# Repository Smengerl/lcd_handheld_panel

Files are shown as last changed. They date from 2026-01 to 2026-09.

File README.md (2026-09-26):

# Wireless Smart Home Control Panel

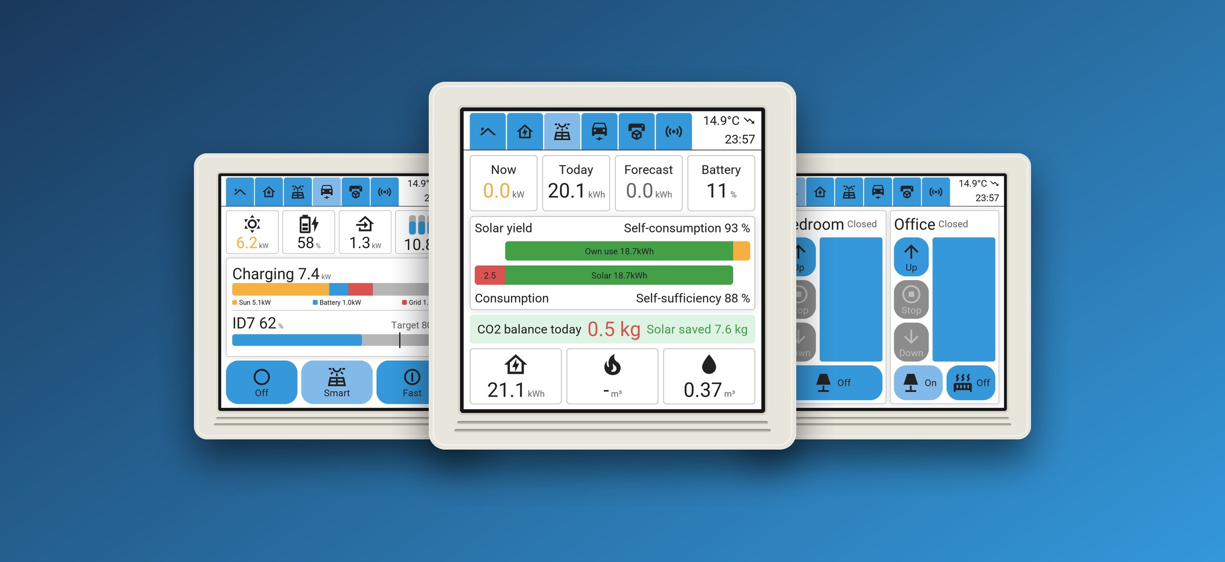
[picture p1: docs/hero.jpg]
Smart home control panel





A 3D-printed, battery-powered 4″ touchscreen (480×480) for Home Assistant, built with ESPHome and LVGL. It charges wirelessly via Qi and snaps onto its charger with a MagSafe-compatible magnetic ring.

## Table of Contents
- [Design](#design)
- [Examples](#examples)
- [3D-Printed Parts](#3d-printed-parts)
- [Standard Hardware](#standard-hardware)
- [Assembly](#assembly)
- [Software](#software)
- [Development](#development)
- [License](#license)
- [Authors](#authors)

## Design

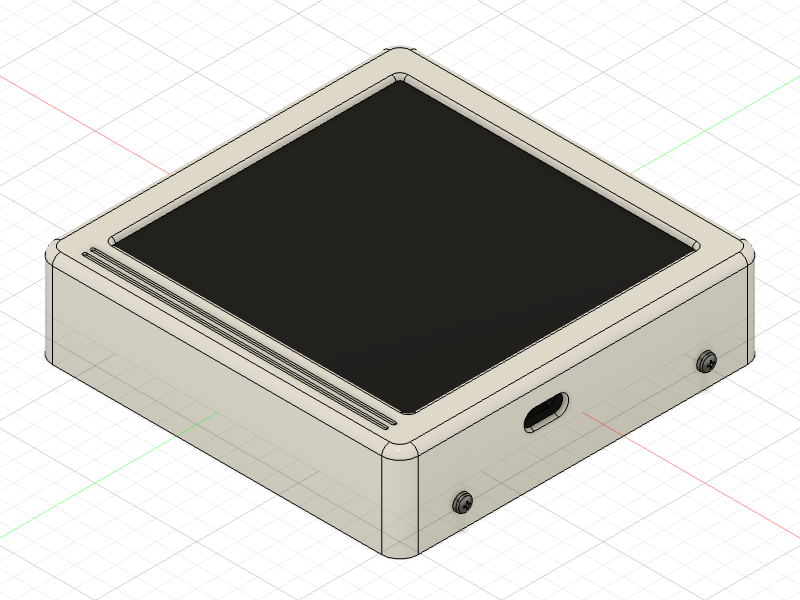
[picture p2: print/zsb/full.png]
Assembly overview


## Examples

Some of the pages I use on my own panels (ESPHome + LVGL, 480×480 px). The images are clean renderings of the real screens, drawn from the actual layout and design tokens.

| | | |
| :---: | :---: | :---: |
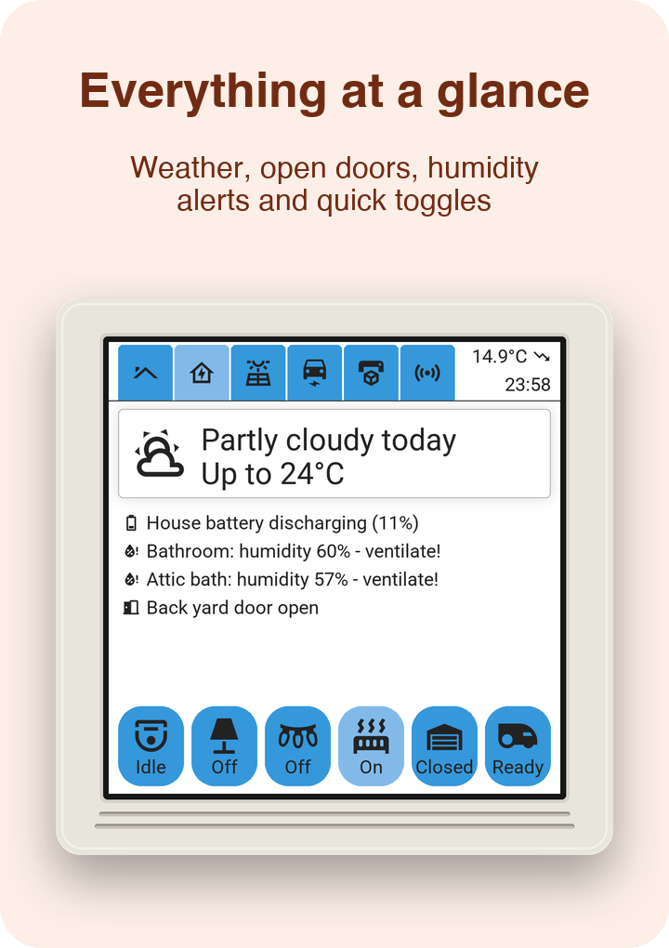
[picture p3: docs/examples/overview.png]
Overview page
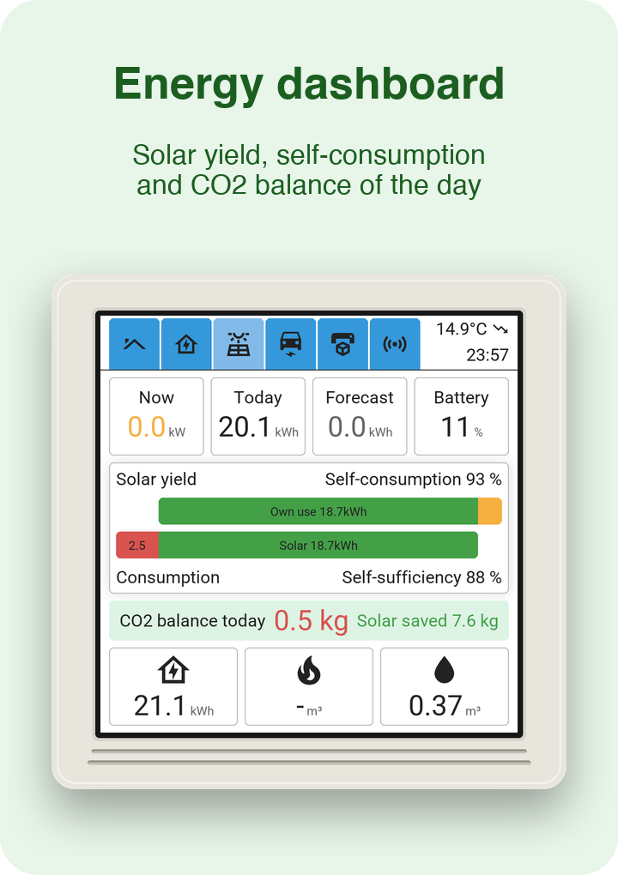
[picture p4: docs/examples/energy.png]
Energy page
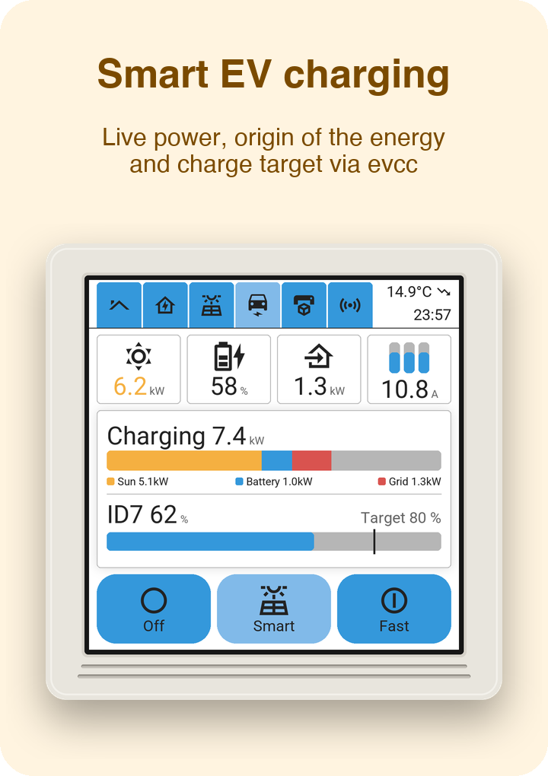
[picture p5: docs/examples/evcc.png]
EV charging page
|  |  |  |
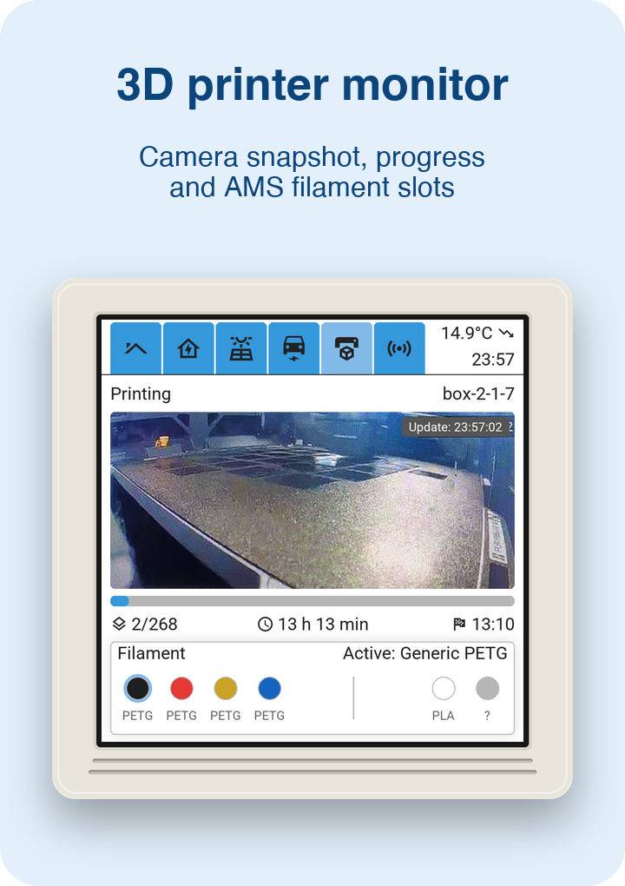
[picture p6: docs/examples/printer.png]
3D printer page
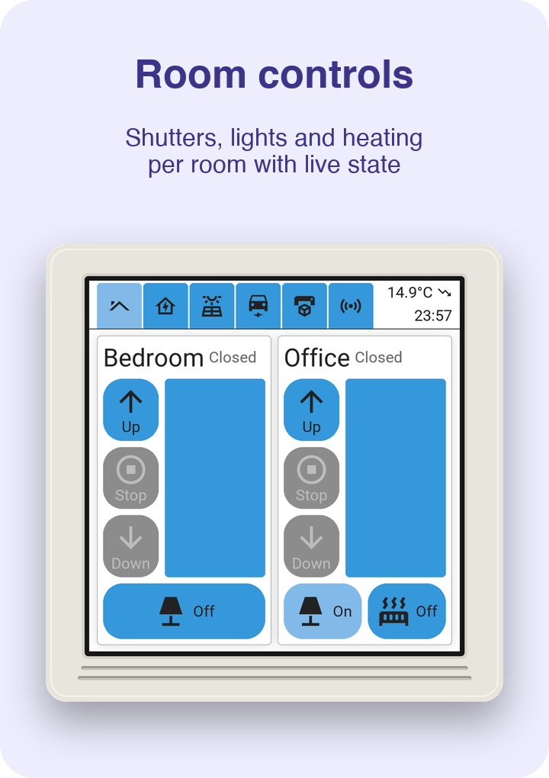
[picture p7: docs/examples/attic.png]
Room controls page
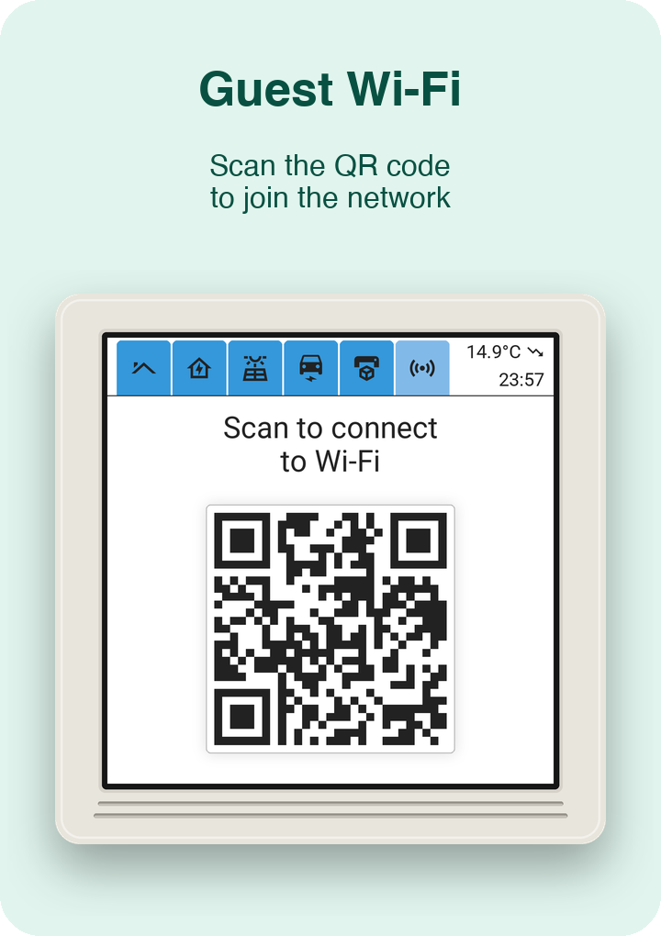
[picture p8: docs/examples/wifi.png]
Guest Wi-Fi page
|  |  |  |
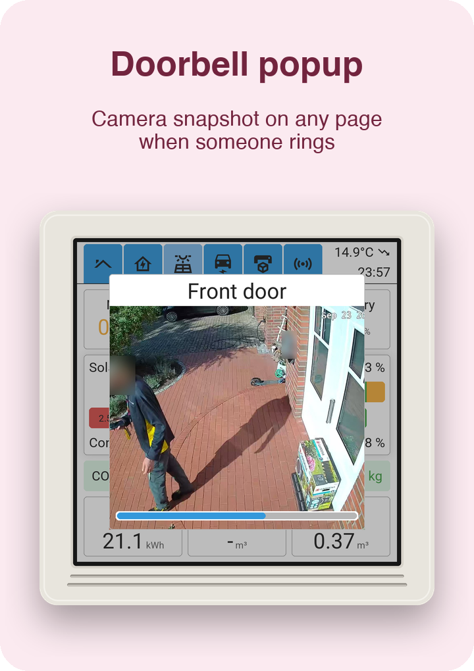
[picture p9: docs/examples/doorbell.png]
Doorbell popup
| |  | |

The example configuration in [`ha_scripts`](./ha_scripts) contains the room-controls page in exactly this design, together with the header, icon tab bar and design tokens, without any dependency on my setup. The other pages depend on specific integrations (solar inverter, [evcc](https://evcc.io), Bambu Lab printer, doorbell camera) and are shown here as inspiration.

## 3D-Printed Parts

See the `print/stl/` and `print/png/` folders for all printable parts and preview images.

Print settings: PETG, 0.2 mm layer height, no supports.

| Filename | Thumbnail | Required | Notes |
| --- | ---| --- | ----- |
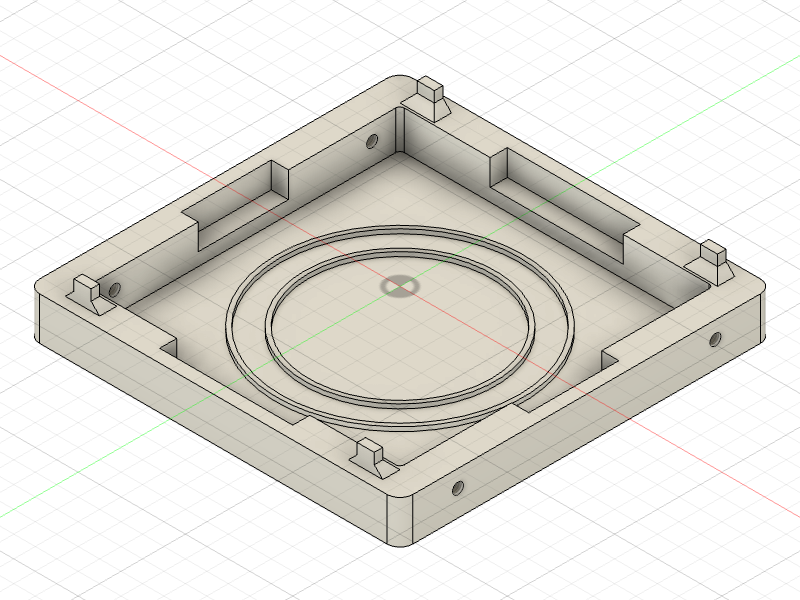
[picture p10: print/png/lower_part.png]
Lower part
| `./print/stl/lower_part.stl`  |  | 1 | |
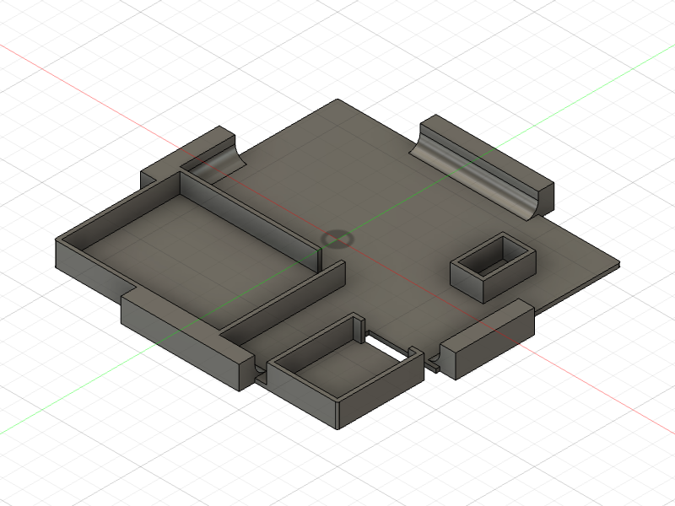
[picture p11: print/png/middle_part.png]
Middle part
| `./print/stl/middle_part.stl` |  | 1 | |
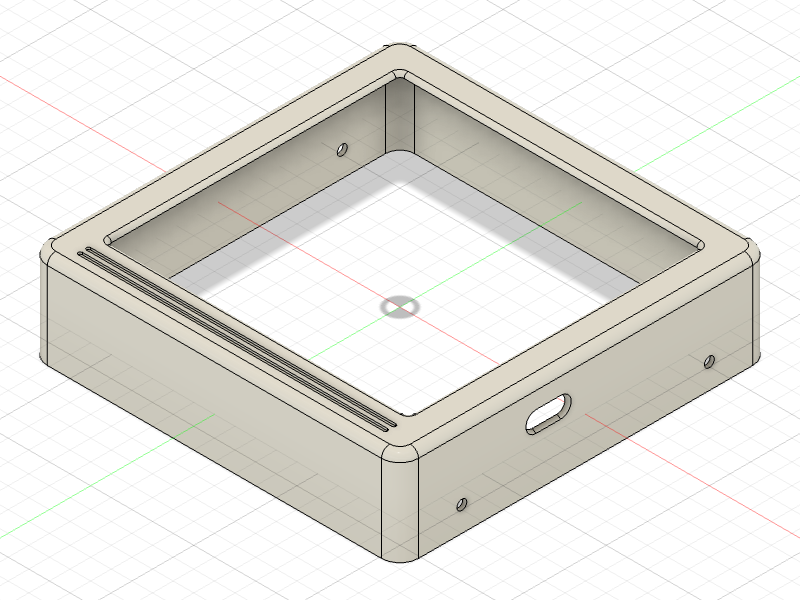
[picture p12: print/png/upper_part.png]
Upper part
| `./print/stl/upper_part.stl`  |  | 1 | |

## Standard Hardware

- Display: Guition ESP32-S3-4848S040 — 4″ IPS, 480×480, ST7701S display driver, GT911 touch, ESP32-S3 on board: https://de.aliexpress.com/item/1005006622809642.html
- Qi wireless charging receiver with integrated charge controller: https://de.aliexpress.com/item/1005005909809714.html
- MagSafe-compatible magnetic ring: https://de.aliexpress.com/item/1005006588934001.html
- LiPo battery 3.7 V, 500 mAh: https://de.aliexpress.com/item/1005006646150179.html
- 4 sheet metal screws, 8 mm

## Assembly

- Glue the magnetic ring and the charging coil into the lower part.
- Route the cables through the opening in the middle part and place the middle part onto the lower part.
- Glue the LiPo battery into the middle part and solder it and the charging coil to the charge controller of the Qi receiver.
- Connect the display to the charge controller and place it on top.
- Finally, place the upper part over the display and fasten it to the lower part using the sheet metal screws.

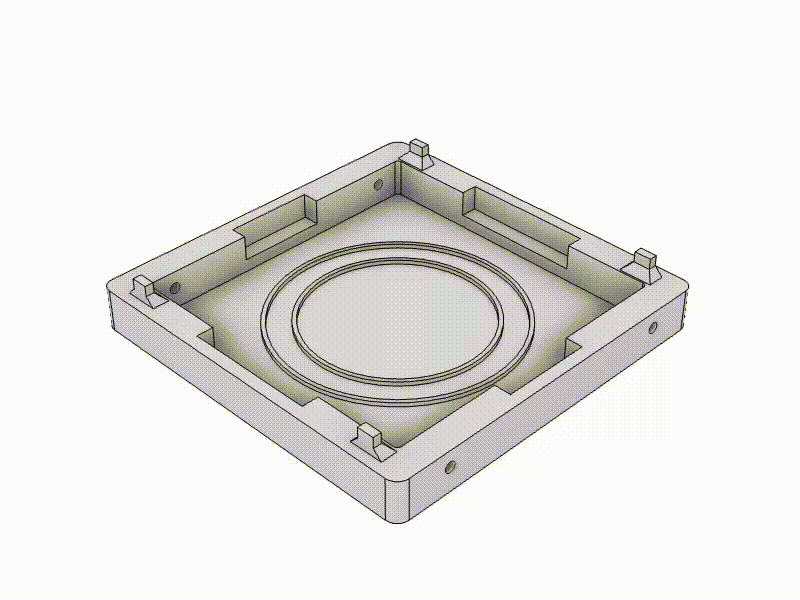
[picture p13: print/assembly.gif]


## Software

The panel can run anything the ESP32-S3 supports. This repository contains an example for Home Assistant with ESPHome and LVGL.

### Prerequisites

- [Home Assistant](https://www.home-assistant.io)
- [ESPHome](https://esphome.io) 2026.8.1 or newer, e.g. the ESPHome Device Builder add-on in Home Assistant

### Installation

1. In the ESPHome Device Builder, create a new device called `handheld-panel` (any name works, as long as the YAML file carries the same name).
2. Copy `handheld-panel.yaml` and the `handheld_panel` folder from [`ha_scripts`](./ha_scripts) into your ESPHome config folder (`[homeassistant]/config/esphome`) and replace the generated `handheld-panel.yaml` with it. Everything else lives inside `handheld_panel/`, so existing files of other devices are not touched.
3. Add the keys from [`secrets.yaml.example`](./ha_scripts/secrets.yaml.example) to your `secrets.yaml` in the same folder (append them if the file already exists) and fill in your own values.
4. Optional: set `outdoor_temperature_entity_id` in `handheld_panel/packages/statusbar.yaml` to a temperature sensor of yours. Without it the header shows `--°C`.
5. Install the configuration on the device from the Device Builder (the first time via USB).
6. Home Assistant discovers the device; add it and you are ready to go.

### What the example does

The example is a minimal version of the panel I use myself. It demonstrates:

- a modular, extensible YAML structure (one package per page, shared base packages)
- design tokens: colors, sizes and fonts are defined in one place (`colors_themes_*.yaml`, `standard_fonts.yaml`); pages only use tokens and a few shared styles
- a header with icon tabs, outdoor temperature and clock, plus screen dimming, a splash screen and an offline overlay
- the room-controls page shown above

It has no dependencies on a specific smart home, so it compiles and runs without matching entities. The shutter buttons only write log lines and the switches toggle locally; the comments in `page_room_controls.yaml` show how to call Home Assistant instead.

## Development

Contributions are welcome!
See `CONTRIBUTING.md` for details and follow the `CODE_OF_CONDUCT.md` when contributing.

All .stl, .png, and assembly pictures are automatically exported via my Fusion add-in, see [here](https://github.com/smengerl/fusion-exporter).

## License

This project is licensed under the Creative Commons Attribution-ShareAlike 4.0 International License (CC BY-SA 4.0) — see `LICENSE.txt` for details or visit http://creativecommons.org/licenses/by-sa/4.0/

## Authors

- Simon Gerlach <https://github.com/Smengerl>

---

If something in this README is missing or unclear, please open an issue in the repository so the instructions can be improved.

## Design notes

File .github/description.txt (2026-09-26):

3D-printed, wirelessly charged 4″ touchscreen panel for Home Assistant (ESPHome + LVGL)

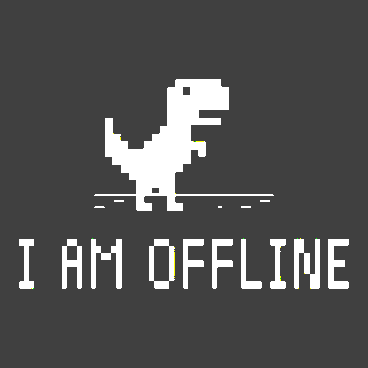
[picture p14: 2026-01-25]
ha_scripts/handheld_panel/images/offline.png

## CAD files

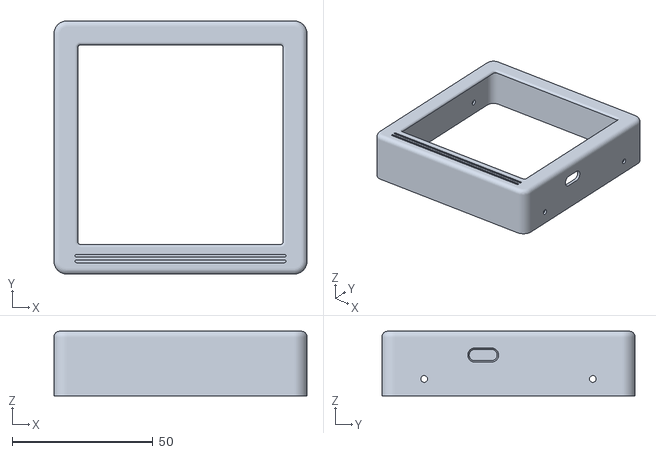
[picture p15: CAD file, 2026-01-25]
print/stl/upper_part.stl
90.0 x 90.0 x 23.0

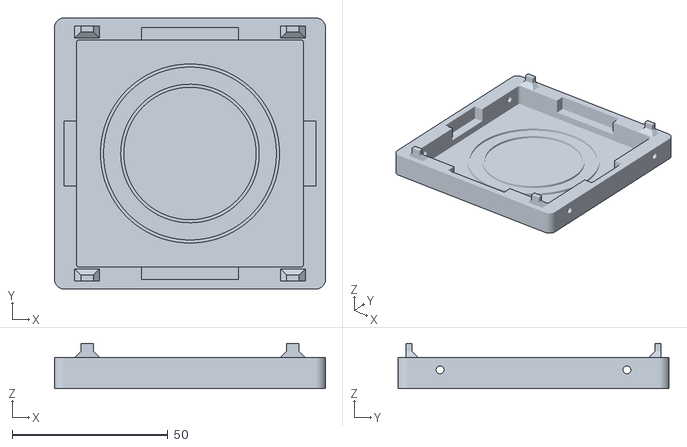
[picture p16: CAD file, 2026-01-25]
print/stl/lower_part.stl
87.0 x 87.0 x 14.5

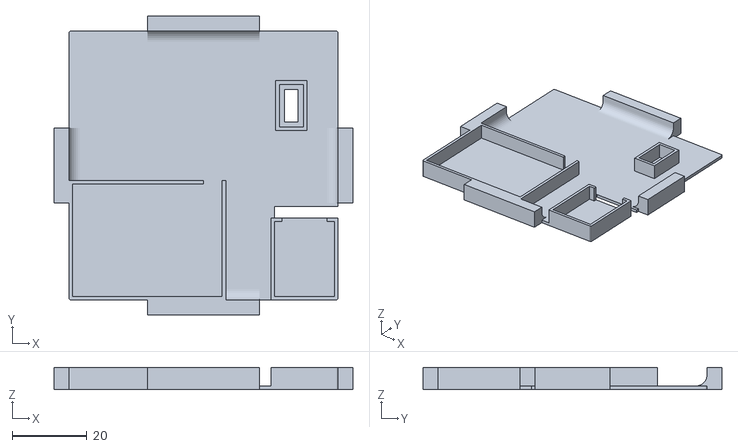
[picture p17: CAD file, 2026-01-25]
print/stl/middle_part.stl
80.0 x 80.0 x 6.00

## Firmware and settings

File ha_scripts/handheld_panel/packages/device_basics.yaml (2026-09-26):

---
#-------------------------------------------
# Display Terminal Device Configuration
# ESP32-S3 based touchscreen display terminal
#-------------------------------------------

substitutions:
  touchscreen_id: my_touchscreen # Touchscreen component ID

#-------------------------------------------
# ESP32-S3 Hardware Configuration
# Optimized for 16MB flash with PSRAM
#-------------------------------------------
esp32:
  board: esp32-s3-devkitc-1
  variant: esp32s3
  flash_size: 16MB
  framework:
    type: esp-idf
    sdkconfig_options:
      COMPILER_OPTIMIZATION_SIZE: y # Optimize for size
      CONFIG_ESP32S3_DEFAULT_CPU_FREQ_240: y # Run at 240MHz
      CONFIG_ESP32S3_DATA_CACHE_64KB: y # 64KB data cache
      CONFIG_ESP32S3_DATA_CACHE_LINE_64B: y # 64-byte cache lines
      CONFIG_SPIRAM_FETCH_INSTRUCTIONS: y # Execute code from PSRAM
      CONFIG_SPIRAM_RODATA: y # Store read-only data in PSRAM

#-------------------------------------------
# PSRAM Configuration
# External RAM for graphics buffers
# See: https://esphome.io/components/psram.html
#-------------------------------------------
psram:
  mode: octal # Octal SPI mode for higher bandwidth
  speed: 80MHz # 80MHz clock speed

#-------------------------------------------
# Logging Configuration
#-------------------------------------------
logger:
  level: info
  logs:
    i2c.idf: info # I2C driver messages
    touchscreen: info # Touch events
    scheduler: none # Suppress scheduler logs

#-------------------------------------------
# System Configuration
#-------------------------------------------

# Home Assistant API with encryption
api:
  encryption:
    key: ${api_key}

# Over-The-Air updates
ota:
  - platform: esphome
    password: ${ota_pw}

#-------------------------------------------
# WiFi Configuration
#-------------------------------------------
wifi:
  ssid: !secret wifi_ssid
  password: !secret wifi_password

  # Fallback access point if WiFi fails
  ap:
    ssid: ${fallback_hotspot_ssid}
    password: ${fallback_hotspot_pw}

#-------------------------------------------
# Network Provisioning
#-------------------------------------------

# Captive portal for WiFi setup via AP mode
captive_portal:

# Dashboard import for easy updates
dashboard_import:
  package_import_url: github://esphome/example-configs/esphome-web/esp32.yaml@main

#-------------------------------------------
# Web Server
# Provides web interface for device management
#-------------------------------------------
web_server:
  port: 80
  version: 3

#-------------------------------------------
# Time Synchronization
# SNTP client for accurate timekeeping
#-------------------------------------------
time:
  - platform: sntp
    id: clock_timer
    timezone: Europe/Berlin
    servers:
      - 0.pool.ntp.org
      - 1.pool.ntp.org
      - 2.pool.ntp.org
    # Update the header clock minute-aligned (on_time) and right after the NTP
    # sync. time_update is defined in statusbar.yaml (always loaded together
    # with device_basics) and only runs on a valid time.
    on_time_sync:
      then:
        - script.execute: time_update
    on_time:
      - seconds: 0
        then:
          - script.execute: time_update

#-------------------------------------------
# Hardware Outputs
# Physical actuators controlled by the ESP32
# (Internal definitions, not exposed to Home Assistant)
#-------------------------------------------
output:
  # Display backlight PWM control
  - platform: ledc
    pin: GPIO38
    id: backlight_output
    frequency: 100Hz

  # Built-in 240V relay
  - id: panel_output
    platform: gpio
    pin: 40

#-------------------------------------------
# Lights
# Actuators exposed to Home Assistant
#-------------------------------------------
light:
  ## Expose internal relay as light
  - platform: binary
    name: "Panel Switch"
    id: panel_switch
    output: panel_output

#-------------------------------------------
# I2C Bus Configuration
# Used for GT911 touchscreen controller
#-------------------------------------------
i2c:
  - id: bus_a
    sda: GPIO19
    # WARNING: GPIO45 is a strapping pin on ESP32-S3 and should be used with care.
    # External pull-up/down resistors can cause unexpected boot failures.
    # Consider using a different SCL pin if possible.
    # See: https://esphome.io/guides/faq.html#why-am-i-getting-a-warning-about-strapping-pins
    scl:
      number: GPIO45
      ignore_strapping_warning: true
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

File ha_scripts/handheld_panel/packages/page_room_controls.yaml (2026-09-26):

#-------------------------------------------
# Example page: room controls
#
# Two room cards, each with roller-shutter buttons (up / stop / down), a
# window-style bar showing the closed share of the shutter, and switches for
# light (and heater). Same layout as on the author's panel, see
# docs/examples/attic.png.
#
# This is a DEMO without any dependency on a specific smart home: the shutter
# buttons only write a log line, the switches toggle locally. The comments at
# each on_click show how to call Home Assistant instead; add homeassistant
# sensors to reflect the real state (position -> bar + state label, switch
# state -> checked + On/Off).
#-------------------------------------------

substitutions:
  page_room_controls_id: page_room_controls_id
  page_room_controls_friendly_name: "Rooms"

lvgl:
  pages:
    - id: $page_room_controls_id
      x: 0
      y: 0
      skip: false
      layout:
        type: grid
        grid_columns: ["${sp_page}px", fr(1), "${sp_gap}px", fr(1), "${sp_page}px"]
        grid_rows: ["${y_content}px", fr(1), "${sp_gap}px"]
        pad_column: 0px
        pad_row: 0px
      width: 100%
      bg_color: ${c_bg}
      bg_opa: cover
      widgets:
        # ---- Bedroom: shutter (buttons + window), switches ----
        - obj:
            grid_cell_row_pos: 1
            grid_cell_column_pos: 1
            grid_cell_x_align: STRETCH
            grid_cell_y_align: STRETCH
            styles: style_card_raised
            scrollable: false
            scrollbar_mode: "OFF"
            pad_all: ${sp_gap}px
            layout:
              type: grid
              grid_columns: [72px, fr(1)]
              grid_rows: [40px, fr(1), fr(1), fr(1), 72px]
              pad_column: ${sp_gap}px
              pad_row: ${sp_gap}px
            widgets:
              # title left, shutter state right
              - obj:
                  grid_cell_row_pos: 0
                  grid_cell_column_pos: 0
                  grid_cell_column_span: 2
                  grid_cell_x_align: STRETCH
                  grid_cell_y_align: STRETCH
                  scrollable: false
                  layout:
                    type: FLEX
                    flex_flow: ROW
                    flex_align_main: SPACE_BETWEEN
                    flex_align_cross: END
                  widgets:
                    - label:
                        text_font: $f_large
                        text: "Bedroom"
                    - label:
                        id: label_shutter_bedroom_state_id
                        styles: style_muted
                        pad_bottom: ${sp_baseline}
                        text: "Closed"
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

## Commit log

2026-01-25 update assembly.gif with new graphics
2026-02-04 Remove unnecessary .DS_Store file from print directory
2026-09-01 Fix broken package paths + adopt local screen_dimming
    - display-terminal-upper.yaml: includes pointed at display_terminal_packages/
    but the files are under packages/ -> main did not compile. Repointed to
    packages/.
    - packages/screen_dimming.yaml: replaced with the local version. Single
    inactivity timer (display_idle_timer) replaces the lvgl on_idle mechanism;
    full-screen touchscreen binary_sensor with delayed_on debounce replaces the
    touchscreen on_touch handler + custom debounce; warning-pulse feature gated
    by a persisted global (switch is restore_mode: DISABLED so it can't clobber
    the restored setting on boot). Owns the 'backlight' light (internal).
    - packages/device_basics.y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
    [device_basics.yaml]
2026-09-03 Refresh example config from current home setup
    Bring the published example in line with the current private config. Still a
    demo: the example page's buttons only write log lines.
    - device_basics.yaml: current ESP32-S3 / ST7701S / GT911 / LVGL setup;
    ledc output renamed GPIO38 -> backlight_output; minute-aligned clock via
    time.on_time / on_time_sync; strapping-pin notes
    - screen_dimming.yaml: follow the backlight_output rename
    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
2026-09-26 README: real doorbell snapshot, hero without text, drop old photos
    - Doorbell example now uses a real front camera snapshot (face and
    house number blurred)
    - Hero banner without title text (the README heading is right above)
    - Remove the old example photos, the example cards replace them
2026-09-26 README and example config for people rebuilding the panel
    - Example config renamed from display-terminal-upper (the author's attic)
    to handheld-panel; all packages live in their own handheld_panel/ folder
    so they don't clash with other ESPHome devices
    - Example updated to the current design: design tokens, icon tab header
    with temperature and clock, new room-controls page (still without any
    dependency on a specific smart home)
    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
